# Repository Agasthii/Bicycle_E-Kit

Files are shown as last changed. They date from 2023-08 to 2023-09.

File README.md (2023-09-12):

# Bicycle_E-Kit
## Overview
Considering the increased popularity of bicycles recently we decided to design a
product which would enhance the overall experience of the rider.
The product includes;
- a dark activated light system.
- anti theft alarm system which gives off an alarm if somebody touches the lock when the bicycle is locked.
- turn indicating signal light system.
- a speedometer.

<p align="center">
  
</p>

## Components,PCB and Enclosure

NE555 timer ICs are used for both the lock and the signal lights.ATMega32
microcontroller is programmed to build the speedometer.
We designed and constructed two PCBs for our system using Altium.Also an
enclosure was designed and constructed using Solidworks software.
Finally the system was fixed on a bicycle to demonstrate the working prototype of
our product.

<p align="center">
  
</p>

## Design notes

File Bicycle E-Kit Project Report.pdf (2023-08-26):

# Bicycle E – Kit

# Engineering Design Project(EN1190) Semester 2

# Detailed Project Report

EN - 08 GROUP

GAMIDU A.G.D. | - 200179H
GUNAWARDENA M.N. | - 200201V

HAPUTHANTHRI H.H.A.M. - 200207U

HEWAVITHARANA M.I. - 200220D

## Abstract

Considering the increased popularity of bicycles recently we decided to design a product which would enhance the overall experience of the rider.The product includes a dark activated light system,anti theft alarm system which gives off an alarm if somebody touches the lock when the bicycle is locked ,turn indicating signal light system and a speedometer.
NE555 timer ICs are used for both the lock and the signal lights.ATMega32 microcontroller is programmed to build the speedometer.
We designed and constructed two PCBs for our system using Altium.Also an enclosure was designed and constructed using Solidworks software.
Finally the system was fixed on a bicycle to demonstrate the working prototype of our product.

## Components

1.ATMega32 mcu

Initially, we planned on using attiny84 due to its small size but due its unavailability in the current market we had to search for alternatives. The only available and suitable replacement was the atmega 32, a 40 pin mcu of which 32 are i/o pins. We tried to go for a smaller mcu like attiny 13, but it did not have the required number of pins. Due to the larger size of the atmega 32 mcu, our final pcb size was larger than initially estimated.

We used an arduino uno board as an isp to program the atmega 32.

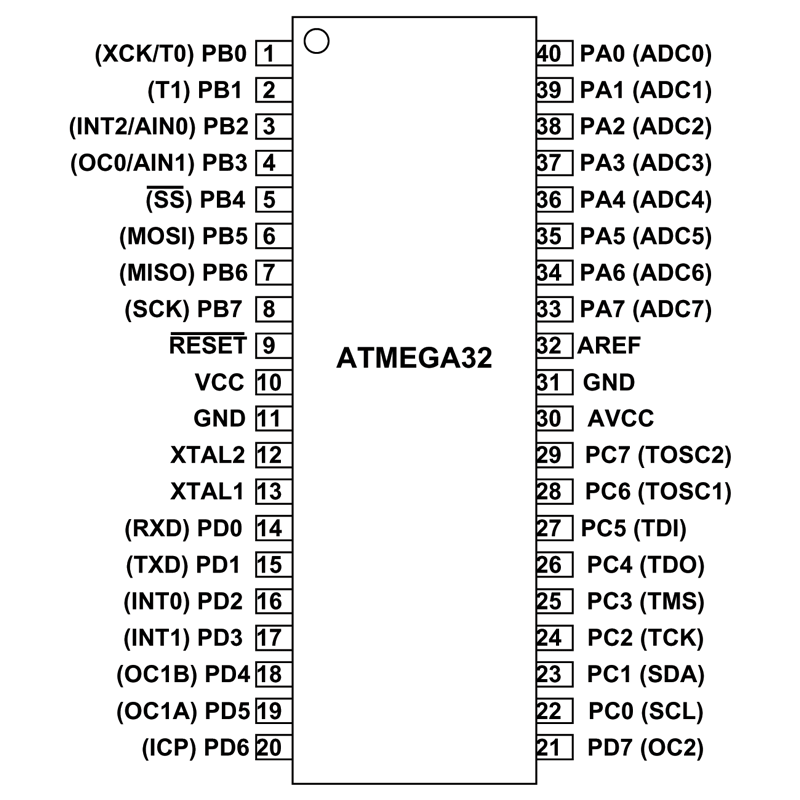
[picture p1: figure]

2. 4 Digit Seven Segment Display

We planned on using a three digit seven segment display as three digits would be enough to show the speed of the bicycle; however, we could not find a common anode three digit seven segment display, therefore we shifted to the 4 digit display. We used a 7447 ic to drive the 7SD.

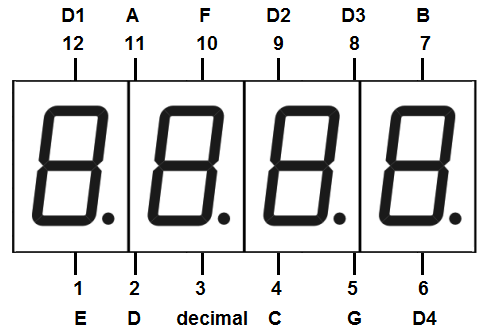
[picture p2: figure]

3.NE555 timer IC

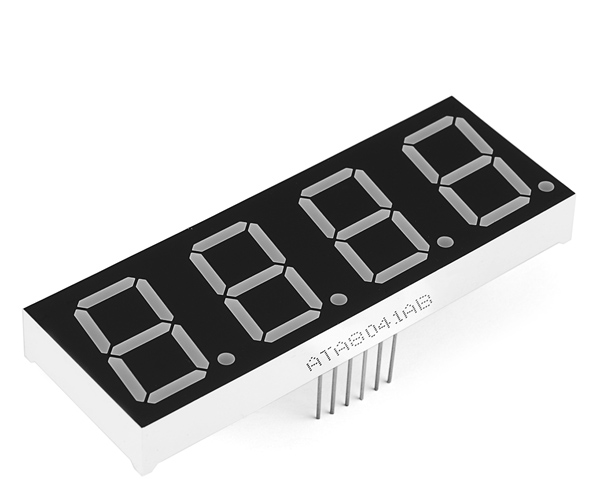
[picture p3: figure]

We used the 8-pin DIP NE555 IC which was commonly available in the Sri Lankan market.In our product, 555 timer acts as an astable multi vibrator.In the signal lights, the output of the IC is directly connected to the lights through a SPDT switch which makes the lights blink with a delay which can be set by changing the capacitor and resistor values.

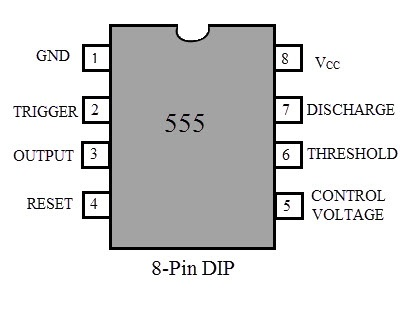
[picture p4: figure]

4.Other components

- 12 V DC Relay
- LDR resistor
- 1N4001 Diode
- 100 K Ohm Potentiometer
- 5 W LED chips
- Switch
- 12 V Battery
- BC 547 Transistor
- Neodymium magnets
- Alarm buzzer

## PCB Design

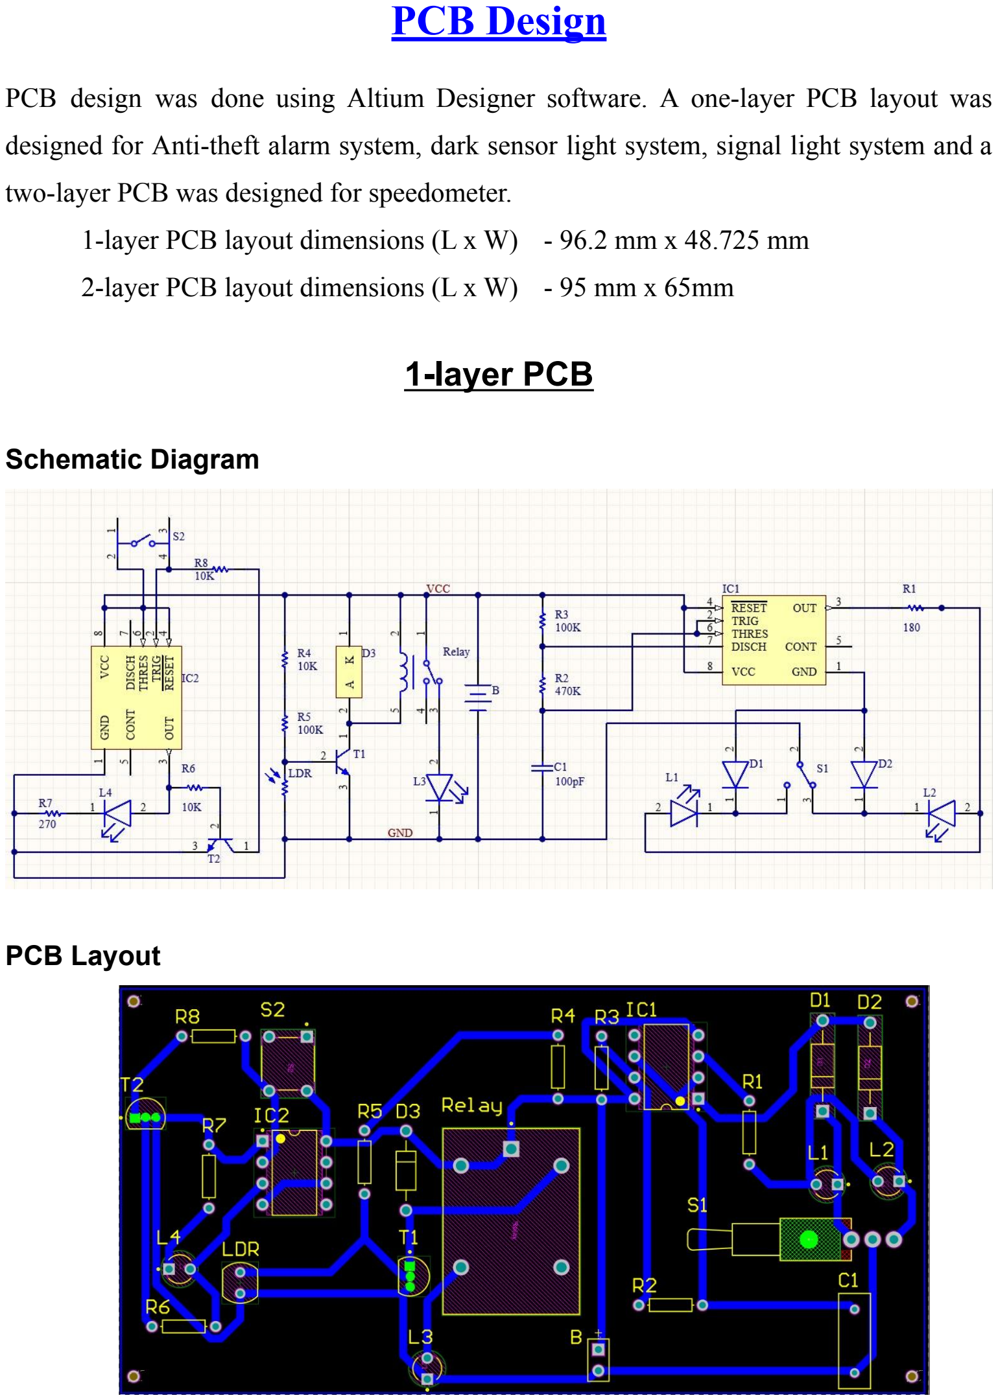
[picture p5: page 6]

PCB design was done using Altium Designer software. A one-layer PCB layout was designed for Anti-theft alarm system, dark sensor light system, signal light system and a two-layer PCB was designed for speedometer.
1-layer PCB layout dimensions (L x W) - 96.2 mm x 48.725 mm
2-layer PCB layout dimensions (L x W) - 95 mm x 65mm

### 1-layer PCB

Schematic Diagram

PCB Layout

3D view of the PCB

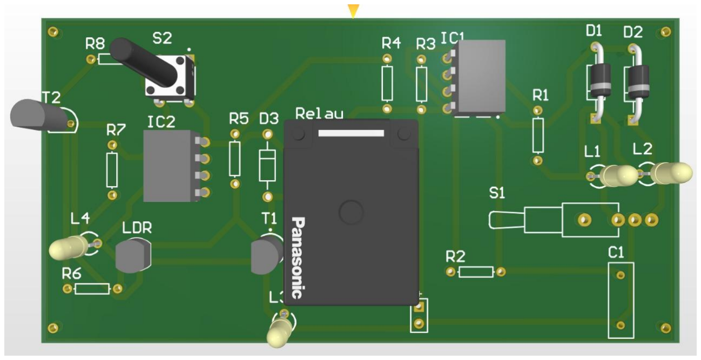
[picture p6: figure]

### 2-layer PCB

Schematic diagram

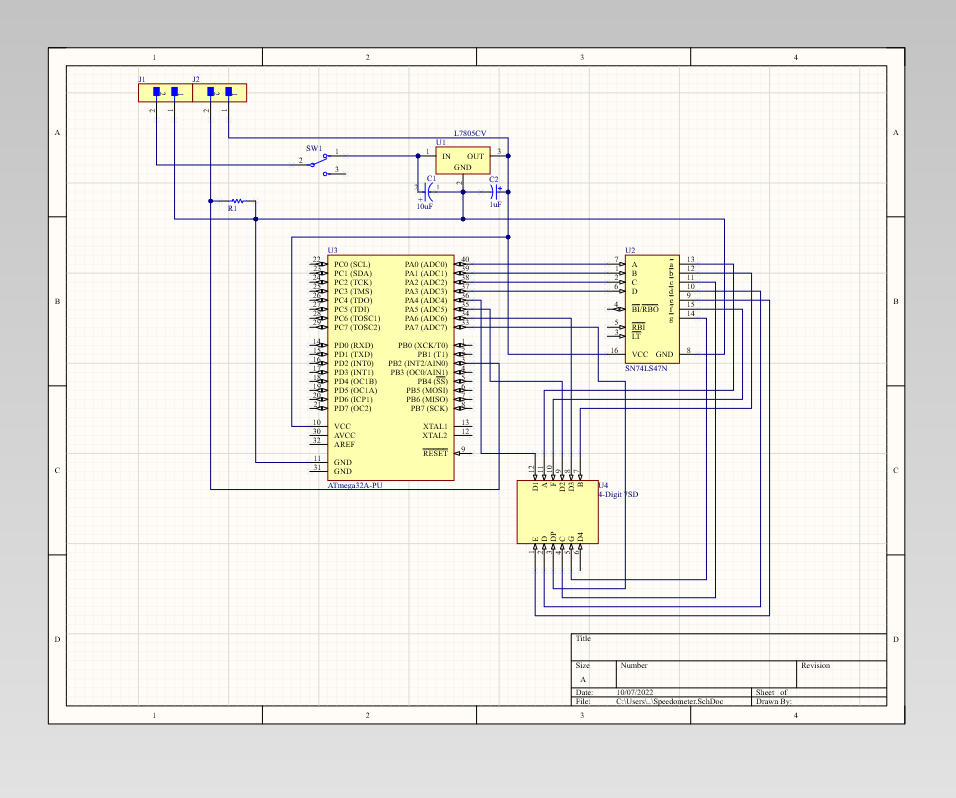
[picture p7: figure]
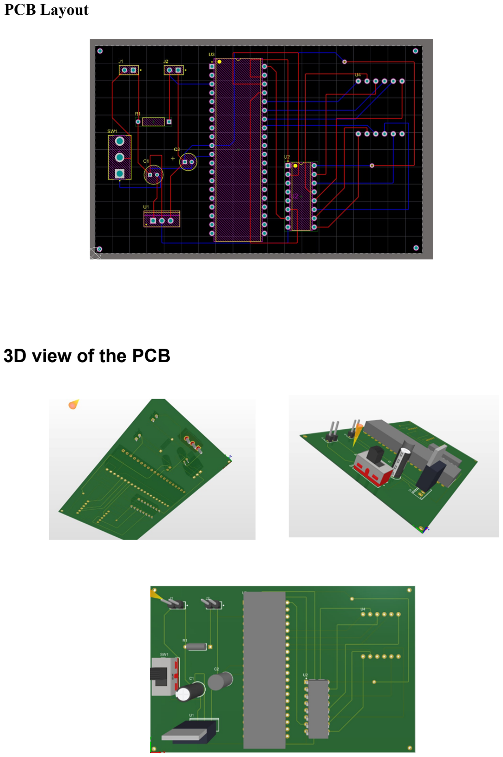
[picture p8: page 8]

PCB Layout

3D view of the PCB

## Enclosure Design

After the PCB design was finalized, a Solid works design for the enclosure was created.

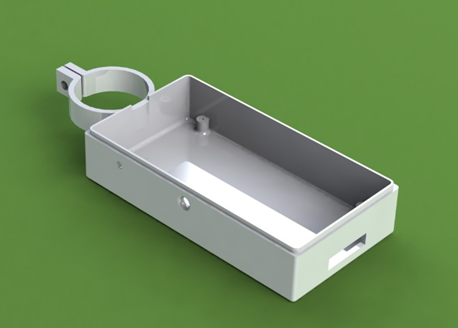
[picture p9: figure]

### Side views of the enclosure

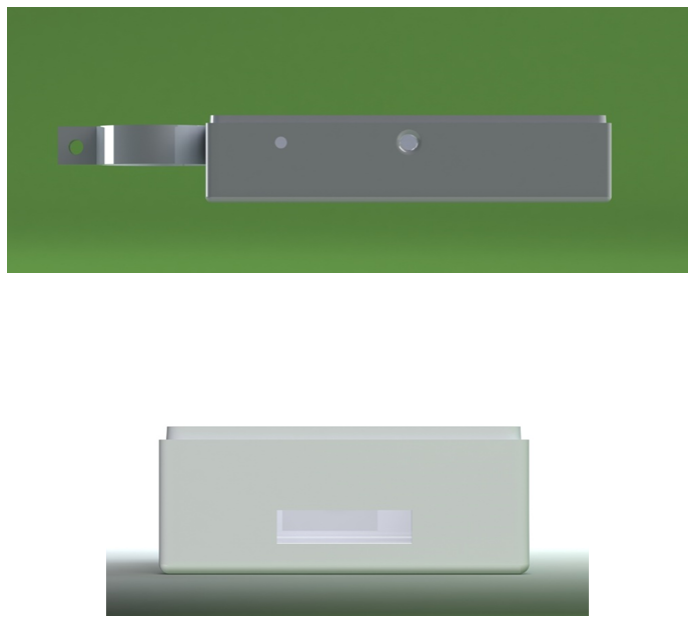
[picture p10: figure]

### Top view of the enclosure

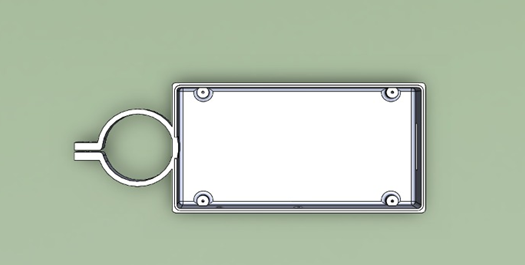
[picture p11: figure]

### Bottom view of the enclosure

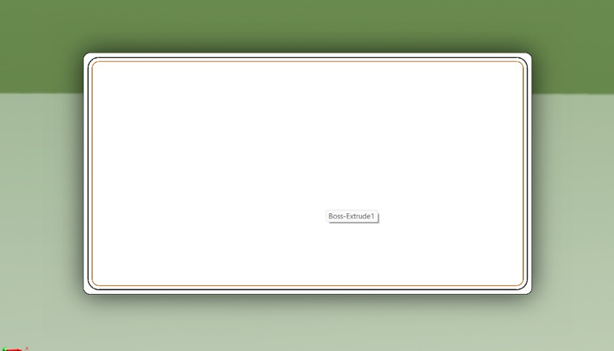
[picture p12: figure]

### 3D view of the Lid for the enclosure

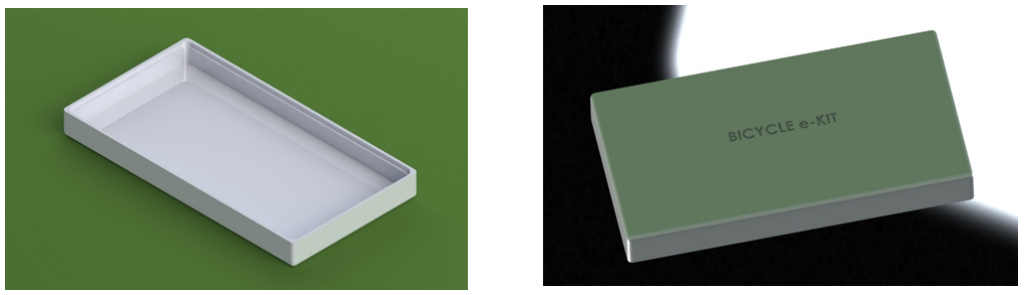
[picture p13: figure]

Bottom view | Top view

Acknowledgements We would like to thank our lecturers, Dr. Ajith Pasqual for the insight given about the process of product design by lecturing us and doing in class activities and Dr Samiru Gayan, for his valuable guidance. We would like to thank each and every person who helped us even in a very small manner in order to make this project a success. We must also thank all the lecturers, instructors, and other academic staff whose contributions and advice indirectly helped us a lot in the completion of this project successfully. Finally, we would like to thank our fellow

friends for sharing their knowledge and experience during the process.

## References

### Understanding the operation of the 555 timer:

### https://www.electronicshub.org/understanding-555-timer/

### Guide on programming the mcu:

### https://www.google.com/amp/s/www.instructables.com/Programming-A

TMEGA32-or-Any-Other-AVR-Using-Arduin/%3famp_page=true (https://www.google.com/amp/s/www.instructables.com/Programming-ATMEGA32-or-Any-Other-AVR-Using-Arduin/%3famp_page=true)

### For the Altium design:

### https://www.altium.com/documentation/altium-designer/tutorial-complet

e-design-walkthrough (https://www.altium.com/documentation/altium-designer/tutorial-complete-design-walkthrough)

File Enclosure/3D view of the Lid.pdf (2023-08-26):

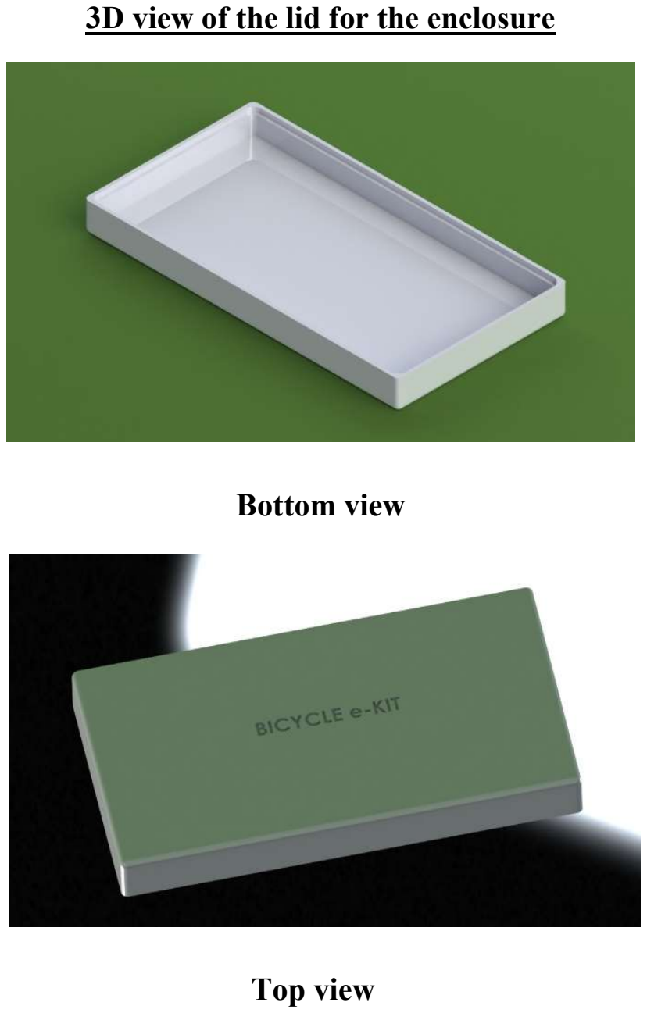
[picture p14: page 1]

3D view of the lid for the enclosure

Bottom view

Top view

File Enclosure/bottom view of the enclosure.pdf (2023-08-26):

Bottom view of the enclosure

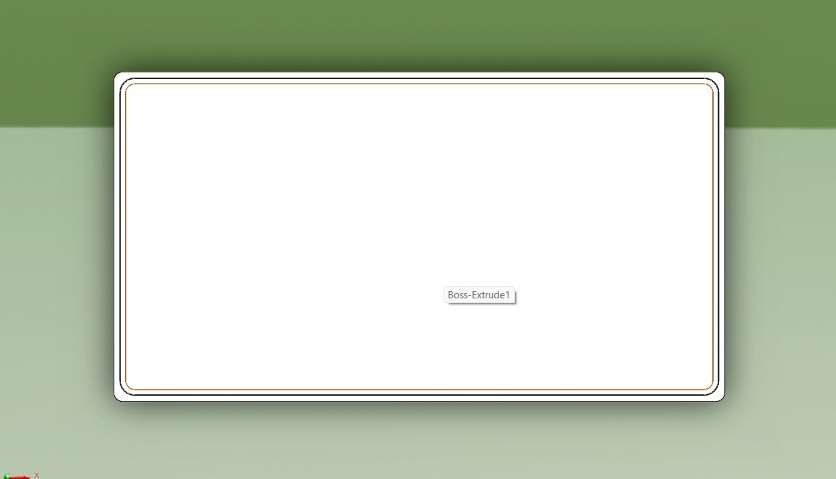
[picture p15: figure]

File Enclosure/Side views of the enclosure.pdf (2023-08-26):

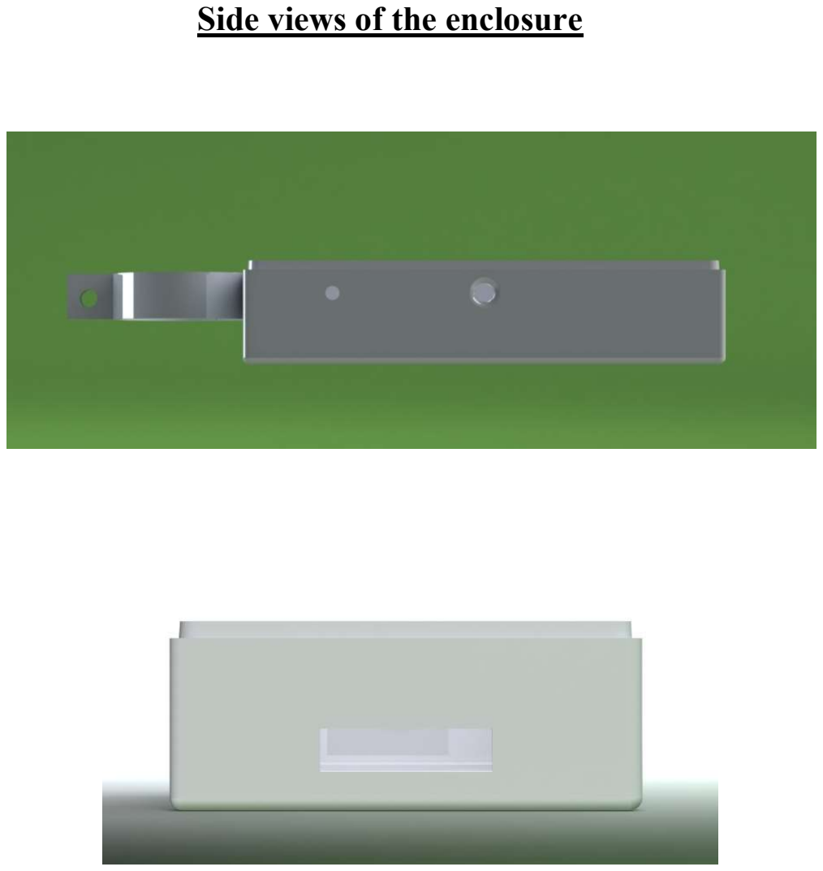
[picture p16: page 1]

Side views of the enclosure

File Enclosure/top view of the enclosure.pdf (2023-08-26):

Top view of the enclosure

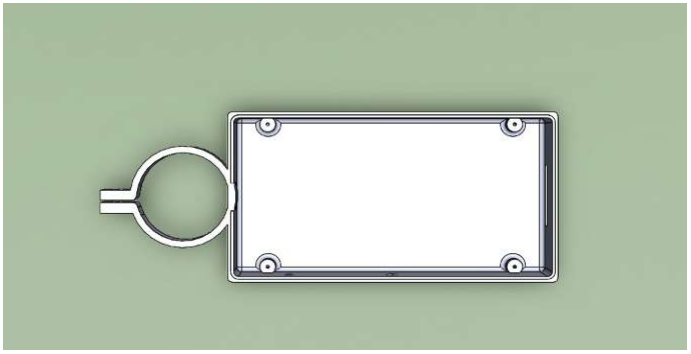
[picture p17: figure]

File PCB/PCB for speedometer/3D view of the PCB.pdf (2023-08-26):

3D view of the PCB

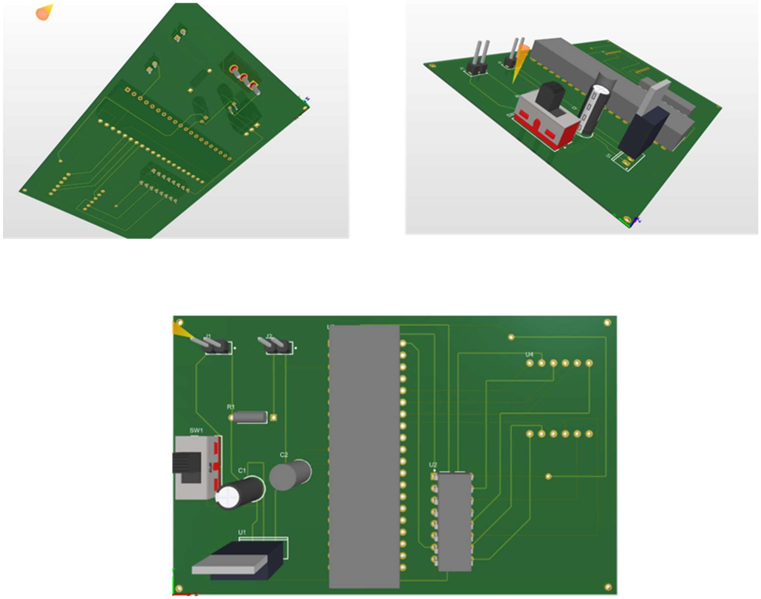
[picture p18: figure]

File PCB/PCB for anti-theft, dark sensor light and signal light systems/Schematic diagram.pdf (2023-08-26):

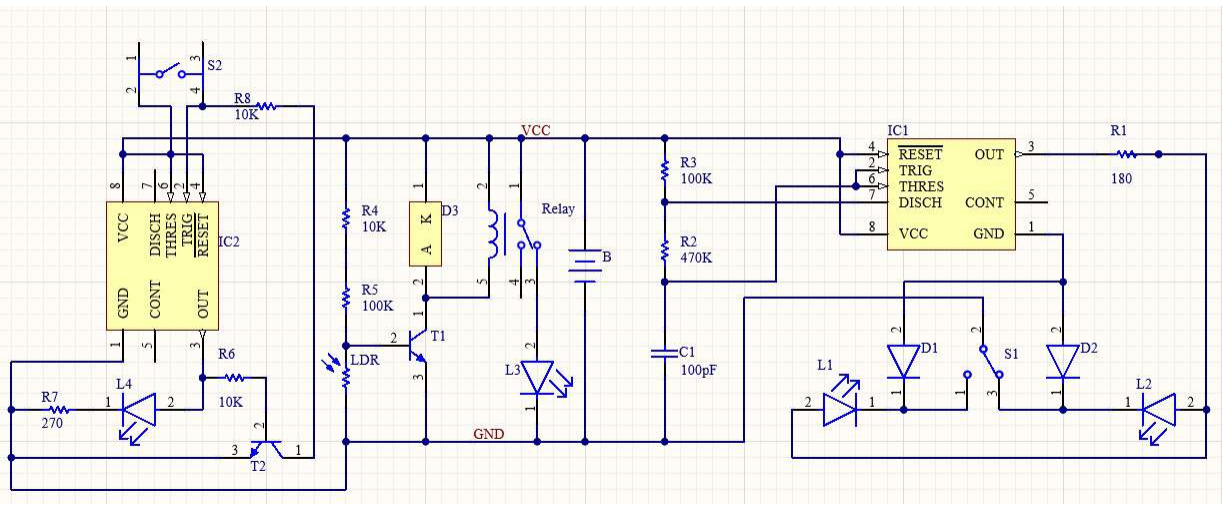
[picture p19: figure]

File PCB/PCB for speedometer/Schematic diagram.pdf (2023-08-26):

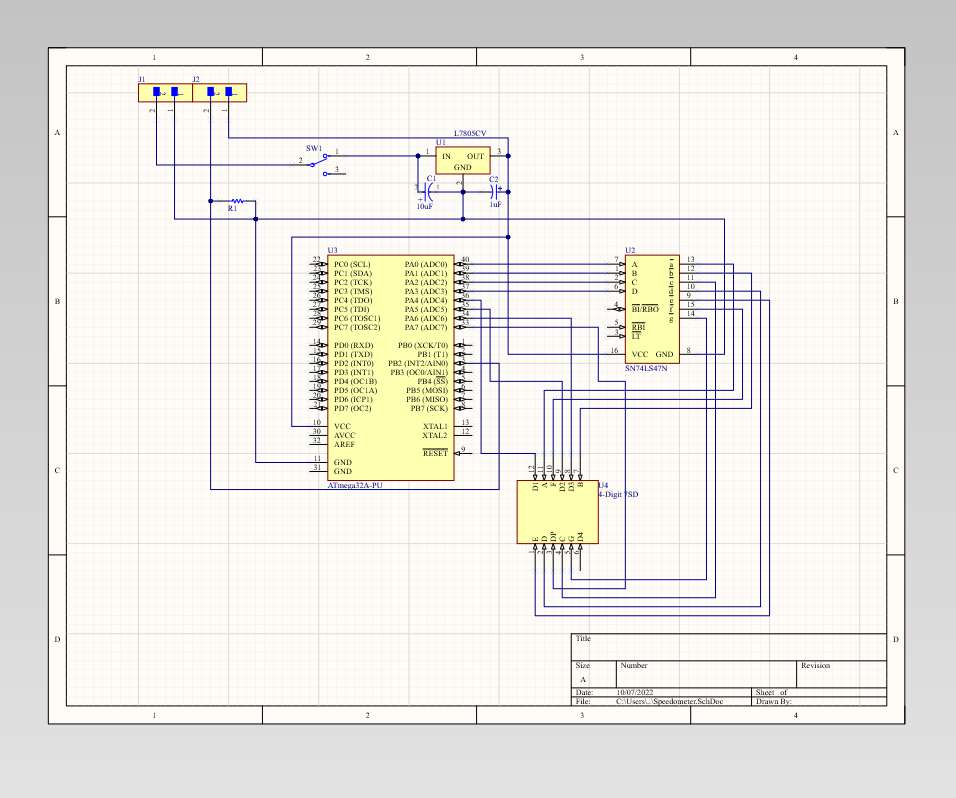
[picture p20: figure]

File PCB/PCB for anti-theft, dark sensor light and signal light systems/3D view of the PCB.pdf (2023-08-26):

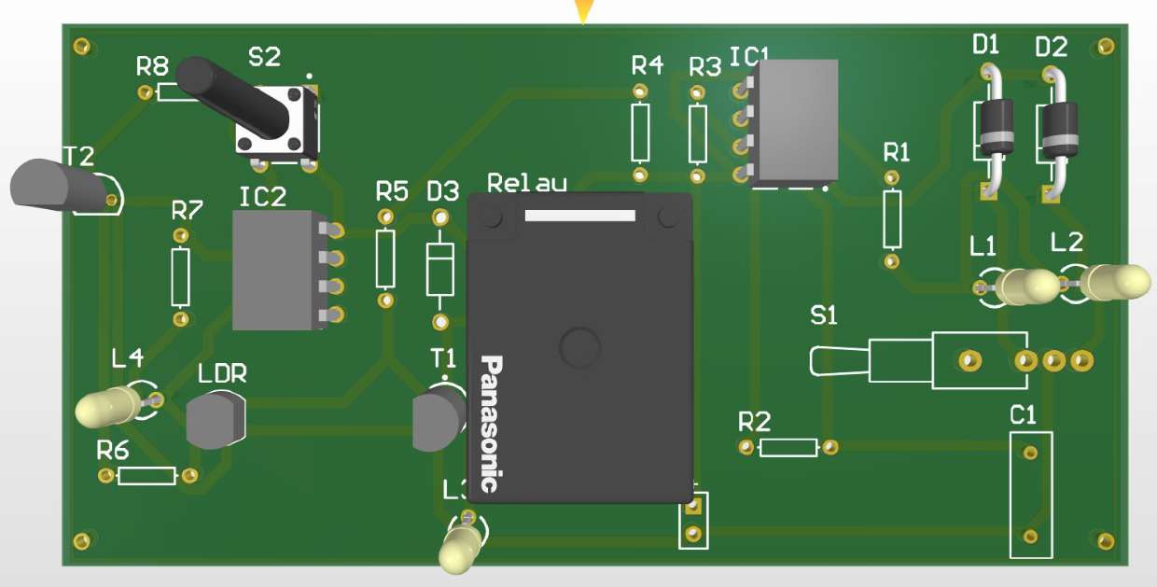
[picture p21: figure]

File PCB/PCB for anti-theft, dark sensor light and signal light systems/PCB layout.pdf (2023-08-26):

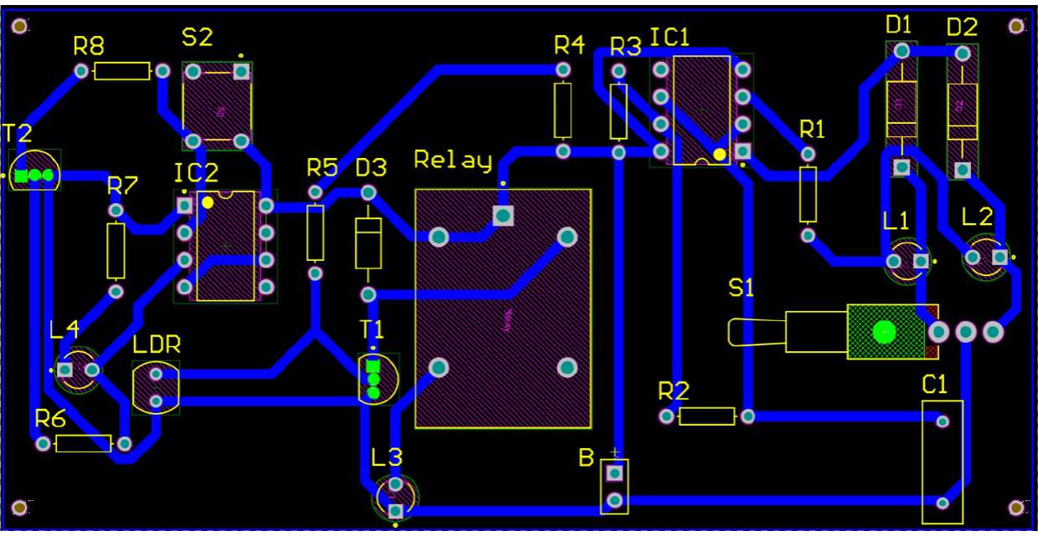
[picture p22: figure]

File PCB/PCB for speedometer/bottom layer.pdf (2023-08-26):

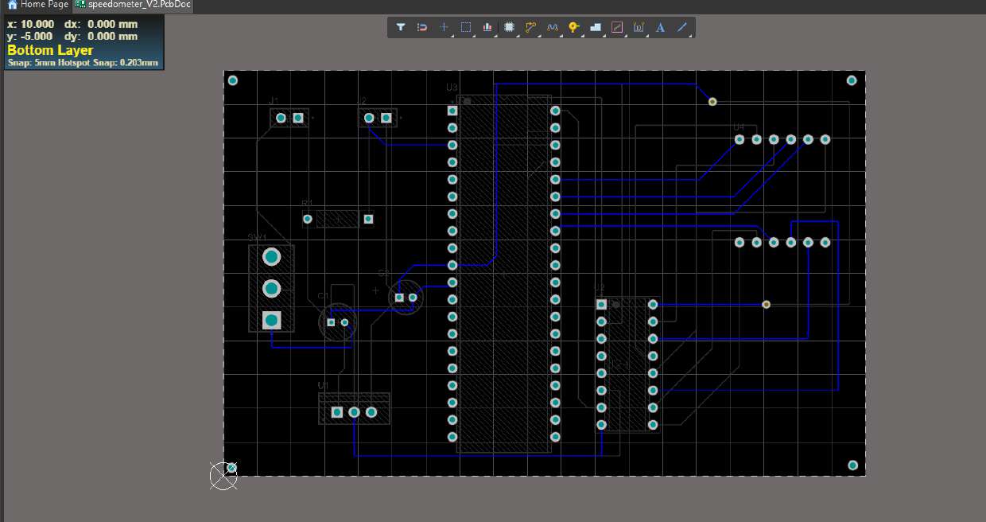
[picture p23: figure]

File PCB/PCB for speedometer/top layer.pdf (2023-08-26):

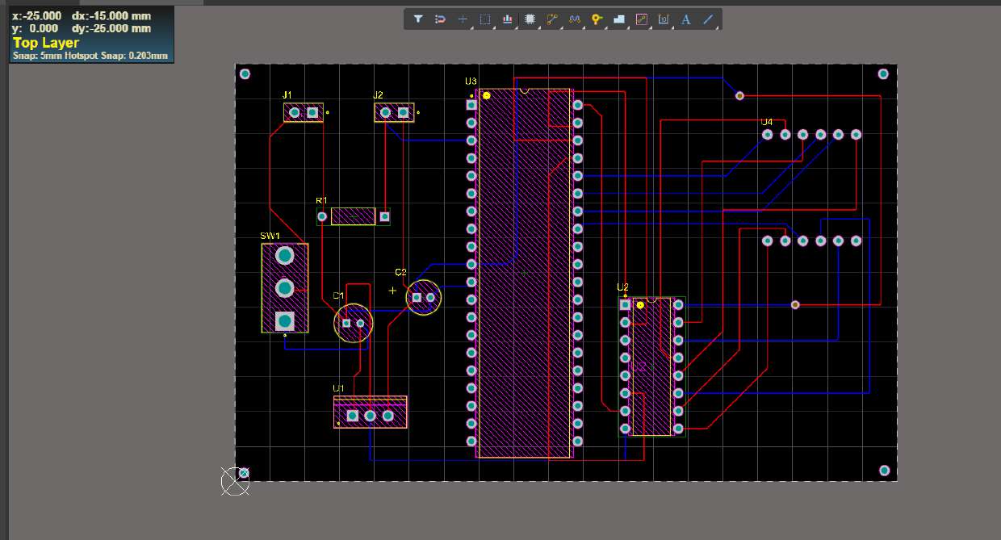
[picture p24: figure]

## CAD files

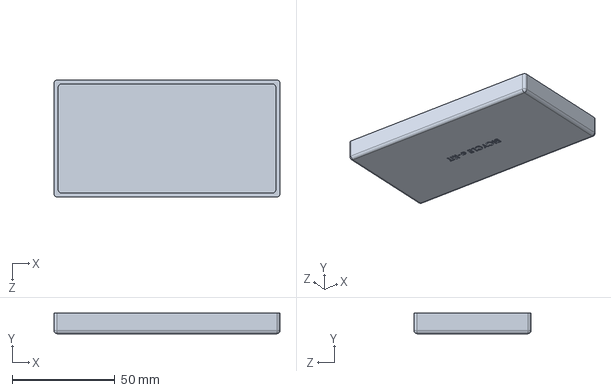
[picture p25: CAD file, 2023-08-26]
Enclosure/Lid of the enclosure.SLDPRT
110.0 x 10.0 x 57.0 mm

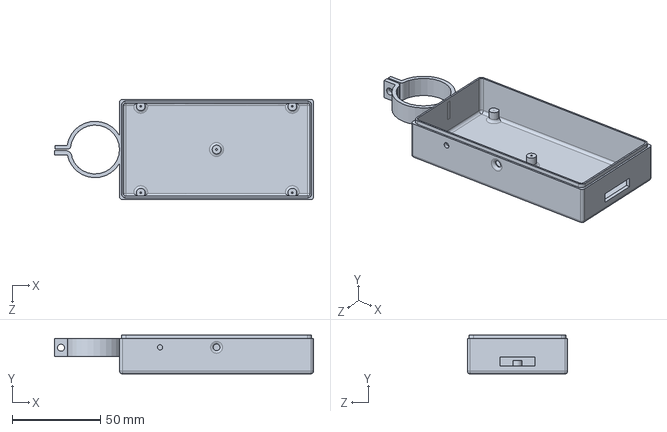
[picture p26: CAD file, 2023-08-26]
Enclosure/Enclosure.SLDPRT
147.0 x 22.0 x 57.0 mm
